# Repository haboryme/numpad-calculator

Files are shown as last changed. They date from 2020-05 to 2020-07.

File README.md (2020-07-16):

# zz15z3oled  

A numpad with a calculator and a 3D printed case 

The calculator itself:
Built on a Pro Micro (Atmega32u4) and paired with a 124x68 OLED screen.  
avr-gcc doesn't support the double type, I used the avr_64f library to emulate double precision using uint64_t.  
I removed some lines of code from avr_f64, you can find the original post from the author along with some interesting discussions (in german) here : https://www.mikrocontroller.net/topic/85256.  
With the current settings overflow leads to NaN and underflow to 0.  

All the logics for the calculator itself are coded in the keymap.c file.   
It follows the behaviour of the Windows (10) calculator. 
Only divide, subtract, add and multiply are currently supported.  

The board:
4 parts:
- case: 3D printed
- plate: laser cut metal (1.5mm)
- weight (optional): laser cut metal (1.5mm)
- promicro holder: 3D printed
- promicro holder lock: 3D printed

All printing was performed on an Ender 3 with Creality PLA at 215°C, with 0.12mm layers and with supports (simplify3d as slicer).
4.4mm Ø and 3.1mm deep holes should be fitted with M3 brass inserts.
The front circular opening in the case should be fitted with a LEMO 0B femal connector (at least 4 pins).
Only M3 screws are used.

There is NO PCB: this is a handwired build, all switches should be fitted with a diode and connected to the promicro in a column/row fashion (update the configuration file for QMK according to the actual wiring).

It's possible to use a 4-pin JST connector for the screen so that it can easily be disconnected and the plate removed (on the side of the screen keep 1-pin connector that can fit through the opening in the plate).

Files:  
glcfont.c - contains the tileset used for displaying characters on the OLED screen, it can be visualized with https://helixfonteditor.netlify.app/  
rules.mk  
config.h - some optimization available here  
zz15z3oled.c  
zz15z3oled.h - defines the base keymap  
keymaps/default/rules.mk - it must have the SRC += avr_f64.c line so that the compiler knows how to link it.  
keymaps/default/avr_f64.c  
keymaps/default/avr_f64.h  
models/numpad case.stl - 3d model for the case
models/numpad plate.dxf - 2d vector file for the plate
models/numpad weight.dxf - 2d vector file for the weight
models/promicro holder lock.stl - 3d model of the lock that fits on the holder
models/promicro holder.stl - 3d model of the holder
numpad 1.0.skp - sketchup file with all the components available for modification

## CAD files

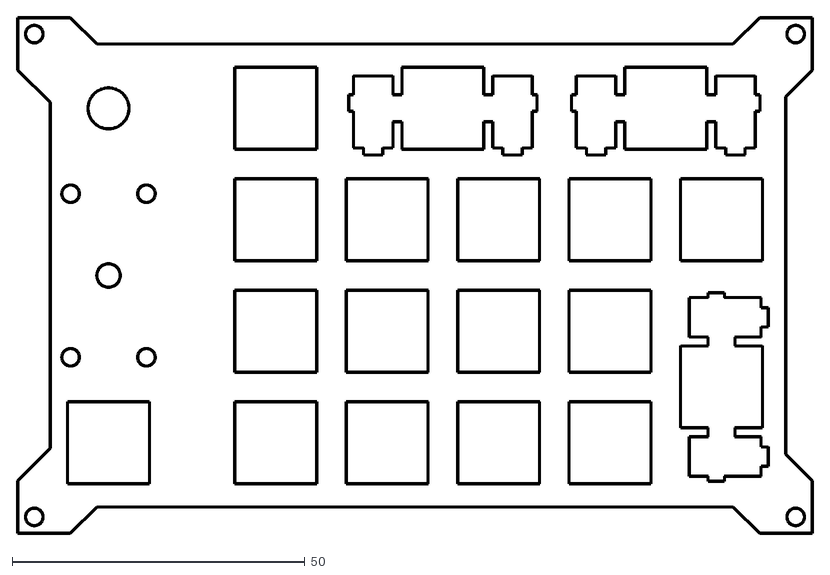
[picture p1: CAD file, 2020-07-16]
models/numpad plate.dxf
136.3 x 88.6

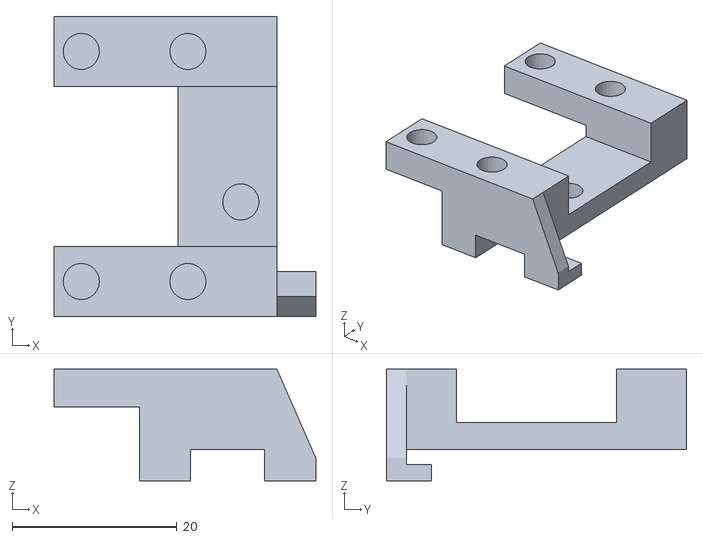
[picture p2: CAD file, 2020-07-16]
models/promicro holder.stl
31.8 x 36.5 x 13.6

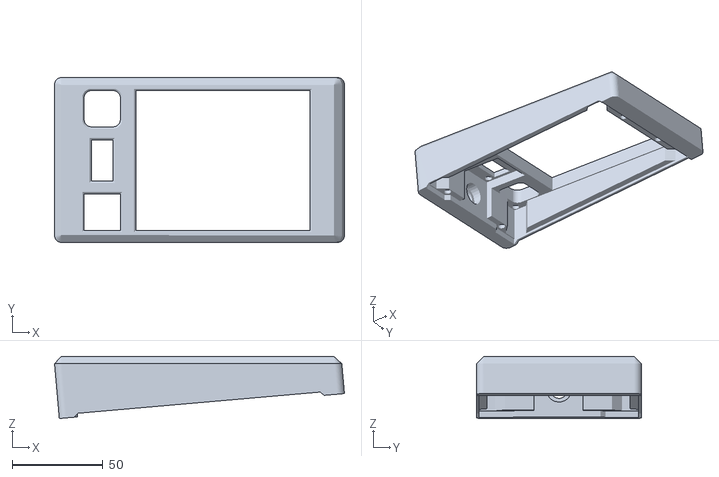
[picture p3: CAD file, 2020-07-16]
models/numpad case.stl
160.2 x 91.1 x 34.3

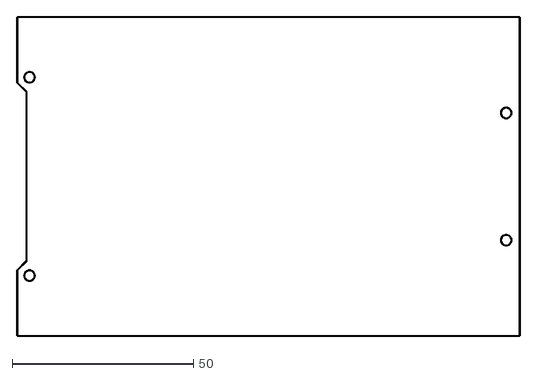
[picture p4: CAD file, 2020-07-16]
models/numpad weight.dxf
139.0 x 88.3

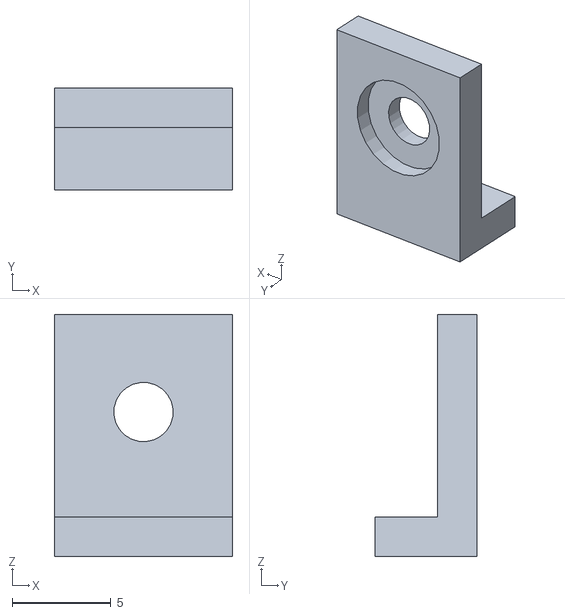
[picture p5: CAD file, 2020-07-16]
models/promicro holder lock.stl
9.00 x 5.15 x 12.2

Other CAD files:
numpad 1.0.skp

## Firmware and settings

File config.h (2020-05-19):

#ifndef CONFIG_H
#define CONFIG_H

#include "config_common.h"

/* USB Device descriptor parameter */
#define VENDOR_ID       0xFEED
#define PRODUCT_ID      0x6060
#define DEVICE_VER      0x0001
#define MANUFACTURER    ms
#define PRODUCT         ms
#define DESCRIPTION     Numpad with basic oled calculator

/* key matrix size */
#define MATRIX_ROWS 6
#define MATRIX_COLS 4

/* key matrix pins */
#define MATRIX_ROW_PINS { F4, F5, F6, F7, B3, B2 }
#define MATRIX_COL_PINS { D4, C6, D7, E6 }
#define UNUSED_PINS

#define ENCODERS_PAD_A { D3 }
#define ENCODERS_PAD_B { D2 }

#define ENCODER_RESOLUTION 4

/* COL2ROW or ROW2COL */
#define DIODE_DIRECTION COL2ROW

/* number of backlight levels */
#define BACKLIGHT_PIN B5
#ifdef BACKLIGHT_PIN
#define BACKLIGHT_LEVELS 3
#endif

/* Set 0 if debouncing isn't needed */
#define DEBOUNCING_DELAY 5

/* Mechanical locking support. Use KC_LCAP, KC_LNUM or KC_LSCR instead in keymap */
#define LOCKING_SUPPORT_ENABLE

/* Locking resynchronize hack */
#define LOCKING_RESYNC_ENABLE

/* Oled */
#define OLED_DISPLAY_128X64
#define OLED_FONT_H "keyboards/zz15z3oled/glcdfont.c"
#define OLED_FONT_START 0
#define OLED_FONT_END 223

/* Tape dance */
//#define TAPPING_TERM 175

/* OPTI */
//#define NO_ACTION_MACRO
//#define NO_ACTION_FUNCTION
//#define NO_ACTION_TAPPING
//#define NO_ACTION_ONESHOT

#endif

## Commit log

2020-07-16 Add files via upload
    promicro holder lock.stl: 3d file for the piece used to lock the promicro onto the holder using a m3 screw (flathead)
    numpad weight.dxf: 2d vector file to cut a metal sheet (1.5mm) for the weight at the bottom
    numpad plate.dxf: 2d vector file to cut the plate (1.5mm) for mounting the switches and stabs.
    promicro holder.stl: 3d file for the promicro holder, should be 3d printed (0.12mm,10% infill, supports recommended). Is also used to hold the MOSFET, screwed to the underside.
    numpad case.stl: 3d file for the case
    numpad 1.0.skp: 3d sketchup file with all the component for easy modification to any of them
    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
    [numpad 1.0.skp, numpad case.stl, numpad plate.dxf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]
2020-07-16 Rename numpad case.stl to models/numpad case.stl
    move to folder
    [numpad case.stl]
2020-07-16 Rename promicro holder lock.stl to models/promicro holder lock.stl
    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
    [promicro holder lock.stl]
2020-07-16 Rename promicro holder.stl to models/promicro holder.stl
    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
    [promicro holder.stl]
2020-07-16 Rename numpad weight.dxf to models/numpad weight.dxf
    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
    [numpad weight.dxf]
2020-07-16 Rename numpad plate.dxf to models/numpad plate.dxf
    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
    [numpad plate.dxf]
2020-07-16 Update README.md
    added info for the case itself
